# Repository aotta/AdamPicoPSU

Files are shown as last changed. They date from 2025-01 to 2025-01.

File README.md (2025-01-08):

# AdamPicoPSU
Yet another Coleco Adam PicoPSU, cheap and compact

It use a 3 amp 12v regulated PSU for input, and a PICOPSU 20 pin for generate the additional -12v and -5v. A lm7905 converts the -12v to the needed -5v too.
In the BOM also a 1n4148 diode, a 10uf caps, the barrell for input the 12v plug and a 6 pin 7x7 push button for the power on/off, and a db-9 pin for connecting to the ADAM.
Further details in the kicad project and in the "jlcpcb/production_files" subfolder

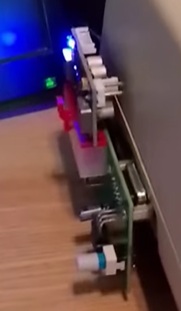
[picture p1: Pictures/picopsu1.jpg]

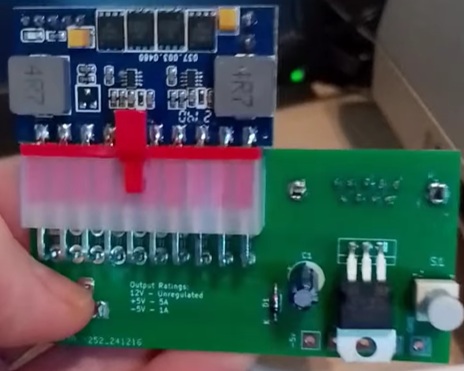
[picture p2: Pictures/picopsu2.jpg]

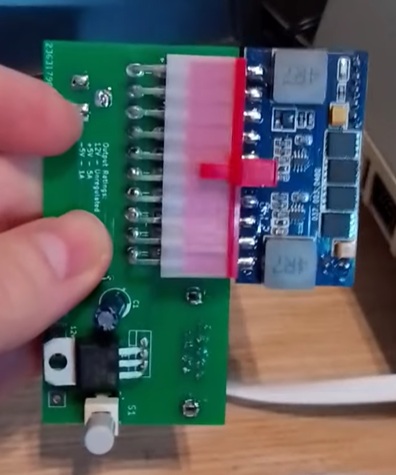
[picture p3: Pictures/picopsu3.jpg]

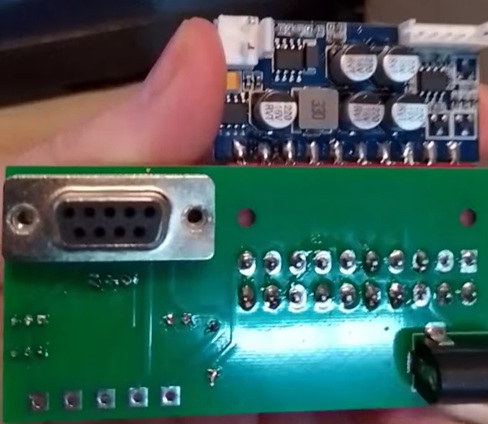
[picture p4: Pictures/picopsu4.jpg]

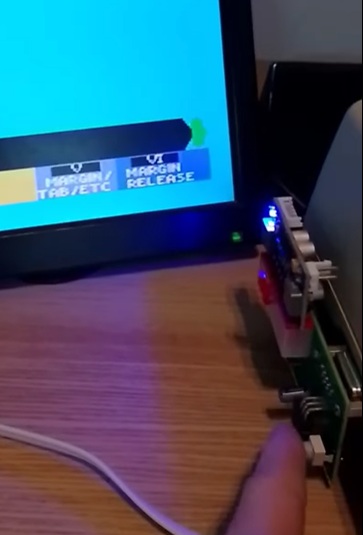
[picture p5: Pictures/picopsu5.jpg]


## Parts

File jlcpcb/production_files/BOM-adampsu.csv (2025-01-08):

Comment | Designator | Footprint | LCSC
10uf | C1 | CP_Radial_D6.3mm_P2.50mm
L7905 | U1 | TO-220-3_Vertical
Barrel_Jack_Switch | J1 | BarrelJack_Horizontal
D_Schottky | D1 | D_DO-34_SOD68_P7.62mm_Horizontal
DB9_Female | J3 | DSUB-9_Female_Vertical_P2.77x2.84mm_MountingHoles
ATX-20 | J4 | Molex_Mini-Fit_Jr_5569-20A2_2x10_P4.20mm_LargeHoles
TL2230EEF140 | S1 | SW_TL2230EEF140
+5V/Orange | TP3 | TestPoint_THTPad_3.0x3.0mm_Drill1.5mm
+12VI/Red | TP2 | TestPoint_THTPad_3.0x3.0mm_Drill1.5mm
-5V/Yellow | TP4 | TestPoint_THTPad_3.0x3.0mm_Drill1.5mm
GND/Green | TP5 | TestPoint_THTPad_3.0x3.0mm_Drill1.5mm
+12VL/Brown | TP1 | TestPoint_THTPad_3.0x3.0mm_Drill1.5mm

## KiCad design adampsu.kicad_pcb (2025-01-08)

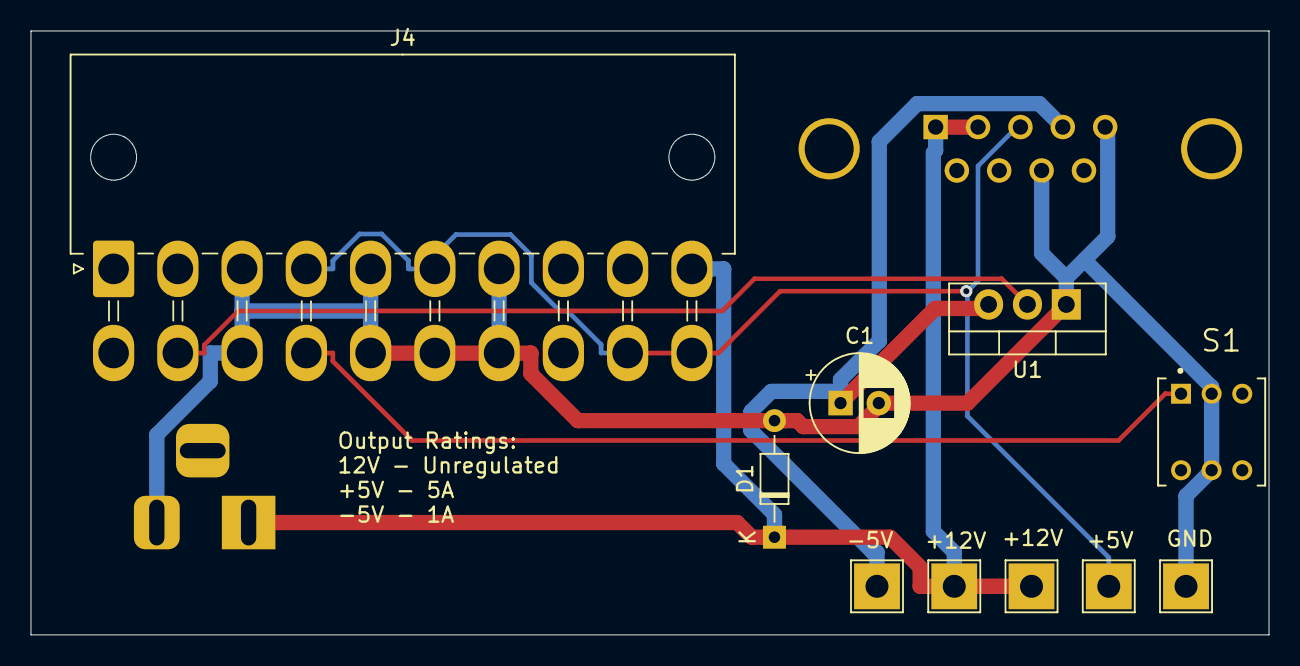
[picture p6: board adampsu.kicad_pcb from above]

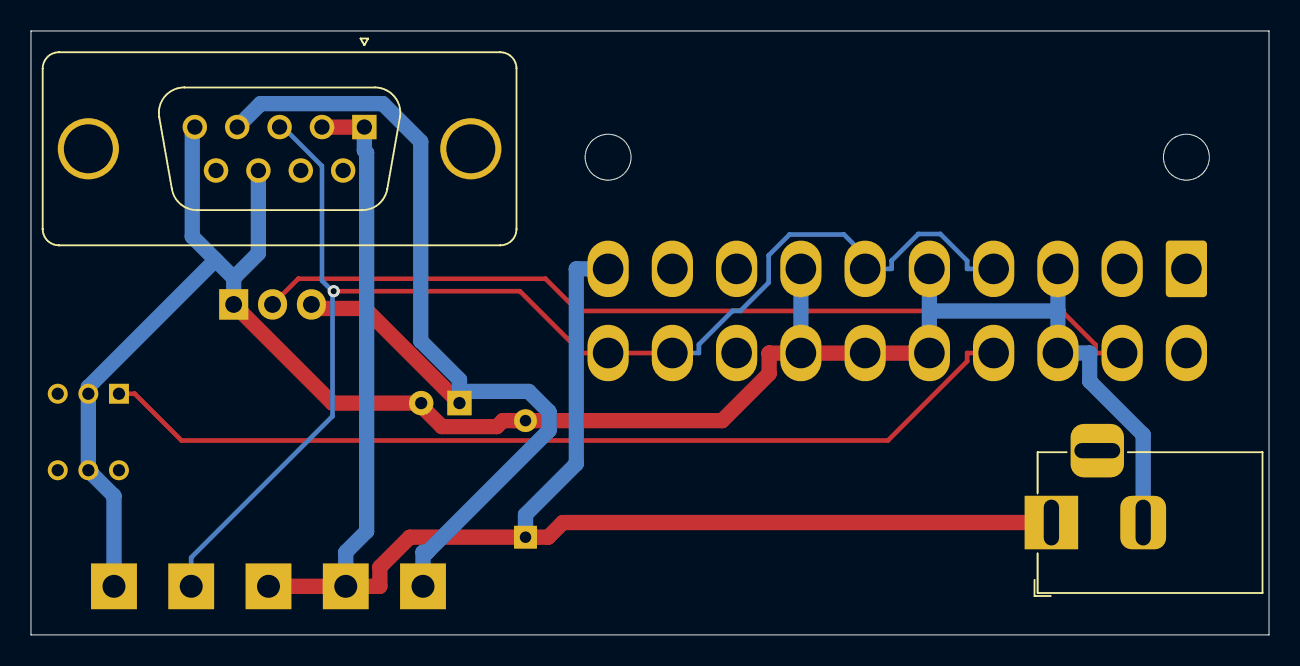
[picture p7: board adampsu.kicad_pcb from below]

Board: 2 copper layers, 80.9 x 39.5 mm, 12 parts (2 on the bottom side), 6 nets.

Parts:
C1: 10uf; CP_Radial_D6.3mm_P2.50mm
D1: D_Schottky; D_DO-34_SOD68_P7.62mm_Horizontal
J1: Barrel_Jack_Switch; BarrelJack_Horizontal
J3: DB9_Female; DSUB-9_Female_Vertical_P2.77x2.84mm_MountingHoles
J4: ATX-20; Molex_Mini-Fit_Jr_5569-20A2_2x10_P4.20mm_LargeHoles
S1: TL2230EEF140; SW_TL2230EEF140
TP1: +12VL/Brown; TestPoint_THTPad_3.0x3.0mm_Drill1.5mm
TP2: +12VI/Red; TestPoint_THTPad_3.0x3.0mm_Drill1.5mm
TP3: +5V/Orange; TestPoint_THTPad_3.0x3.0mm_Drill1.5mm
TP4: -5V/Yellow; TestPoint_THTPad_3.0x3.0mm_Drill1.5mm
TP5: GND/Green; TestPoint_THTPad_3.0x3.0mm_Drill1.5mm
U1: L7905; TO-220-3_Vertical

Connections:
+12V: D1.1 (K), J1.1, J3.1, J3.2, J4.10 (+12V), TP1.1, TP2.1
-12V: J4.12 (-12V), U1.2 (VI)
/+5V: J3.3, J4.4 (+5V), J4.6 (+5V), J4.19 (+5V), J4.20 (+5V), TP3.1
/-5V: C1.1, J3.4, TP4.1, U1.3 (VO)
GND: C1.2, D1.2 (A), J1.2, J3.5, J3.8, J4.3 (GND), J4.5 (GND), J4.7 (GND), J4.13 (GND), J4.15 (GND), J4.16 (GND), J4.17 (GND), S1.2, S1.5, TP5.1, U1.1 (GND)
PWON: J4.14 (PS_ON#), S1.1
